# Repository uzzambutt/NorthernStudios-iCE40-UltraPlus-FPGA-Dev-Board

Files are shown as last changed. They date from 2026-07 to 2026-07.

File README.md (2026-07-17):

# NorthernStudios iCE40-UltraPlus FPGA Dev Board (V2)

<p align="center">
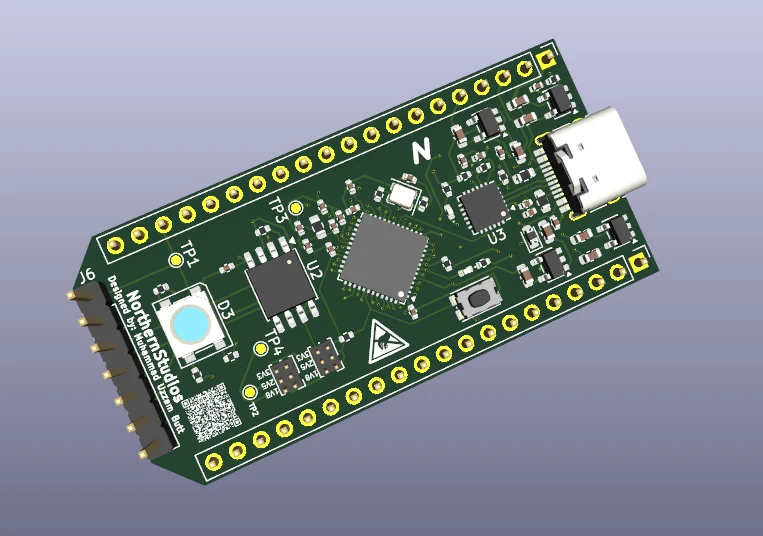
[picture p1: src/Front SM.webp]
NorthernStudios iCE40-UltraPlus FPGA Dev Board V2 - Front Soldermask
  
</p>

<p align="center">
  <b>Designed by: Muhammad Uzzam Butt // Made for Macondo</b>
</p>

<p align="center">
  <a href="https://kicad.org">
    
  </a>
  <a href="https://www.oshwa.org/">
    
  </a>
  <a href="LICENSE">
    
  </a>
</p>

---

## 🌟 Overview

The **NorthernStudios iCE40-UltraPlus FPGA Dev Board (V2)** is a compact, open-source development board designed around the **Lattice iCE40 UltraPlus (iCE40UP5K)** FPGA. Engineered specifically for the **Hack Club Macondo** initiative, this board is tailored for low-power edge computing, machine learning (TinyML), RISC-V softcores, and rapid hardware development.

Featuring an onboard USB-to-UART bridge, a high-capacity 128M-bit SPI Flash, and a highly stable multi-rail power system, it offers a complete, unrestricted environment for developers.

---

## 🛠️ Hardware Specifications

### 🧠 Core FPGA: Lattice iCE40UP5K
* **Logic Cells**: 5,280 Look-Up Tables (LUTs)
* **Block RAM (BRAM)**: 120 Kbit
* **Single-Port RAM (SPRAM)**: 1,024 Kbit (128 KB, ideal for microcontroller program memory)
* **DSP Blocks**: 8 (16x16 multiplier + 32-bit accumulator)
* **Hardened IP**: 2x I2C, 2x SPI
* **Constant Current Drivers**: 3x 24mA dedicated driver outputs (suited for RGB LED control)

### 🔌 Key Components
| Component | Function | Description |
| :--- | :--- | :--- |
| **FPGA** | [Lattice iCE40UP5K-SG48ITR](https://www.latticesemi.com/Products/FPGAandCPLD/iCE40UltraPlus) | SG48 package, 48-pin QFN, highly integrated low-power FPGA. |
| **USB-to-UART Bridge** | [Silicon Labs CP2102N](https://www.silabs.com/interface/usb-bridges/usbtouart/device.cp2102n-a02-gqfn24) | High-speed USB-to-UART bridge for programming and serial debugging via USB-C. |
| **SPI Flash** | Winbond W25Q128JVS (128M-bit / 16MB) | Stores FPGA configuration bitstreams and extra user data or filesystem blocks. |
| **Reference Oscillator** | Seiko Epson SG-210STF (12 MHz) | Ultra-precise active crystal oscillator providing a stable system reference clock. |
| **Power Regulators** | Diodes Inc. AP2112K LDOs | Generates +1.2V (Core), +1.8V (PLL/VCC), +2.5V (Auxiliary), and +3.3V (I/O & Flash) from USB +5V. |
| **USB Connector** | USB Type-C Receptacle (14-Pin) | Handles 5V power supply, programming interface, and UART communications. |

---

## 🎛️ Onboard Interfaces & I/O
* **RGB LED**: Dedicated addressable RGB LED (LED_ARGB) connected to the FPGA's constant current outputs for status and visualization.
* **User I/O**: Multi-pin expansion breakout headers featuring standard 0.1" pitch GPIO pins.
* **Tactile Buttons**:
  * Reset Button
  * User Programmable Button

---

## 📐 PCB Design & Layers

This PCB is designed as a high-density, **4-layer board** utilizing KiCad to ensure clean signal routing, stable ground planes, and dedicated power rails. 

### 🔍 Outer Silkscreen & Soldermask
* **Front View (Main Thumbnail)**:
  Front Soldermask
* **Back View**:
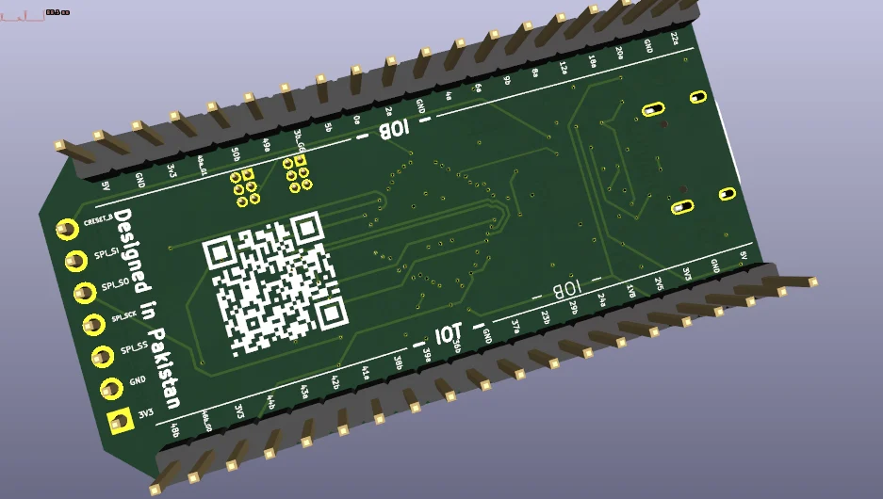
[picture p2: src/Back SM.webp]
Back Soldermask
  

### 🥞 Internal Copper Layer Stackup
* **Layer 1 (L1 - Top Copper / Signals)**:
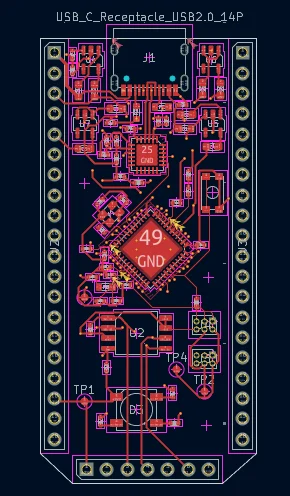
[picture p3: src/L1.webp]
Layer 1 Top Copper
  
* **Layer 2 (L2 - Inner Ground Plane)**:
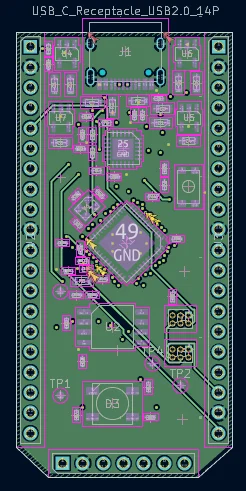
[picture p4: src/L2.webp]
Layer 2 Ground Plane
  
* **Layer 3 (L3 - Inner Power Plane)**:
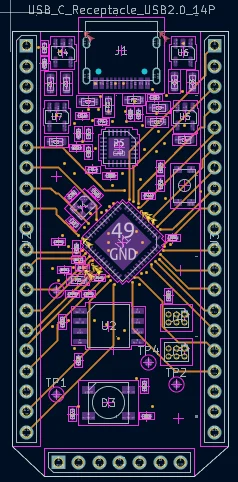
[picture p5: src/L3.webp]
Layer 3 Power Plane
  
* **Layer 4 (L4 - Bottom Copper / Signals)**:
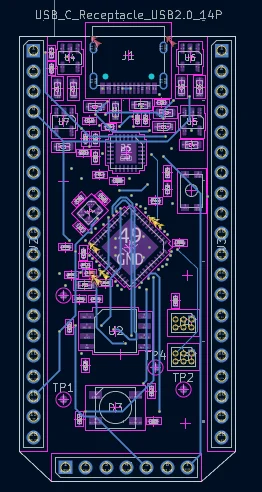
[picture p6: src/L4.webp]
Layer 4 Bottom Copper
  

---

## 📂 Repository Structure

```
├── Models/                     # 3D step models of components
│   └── ICE40UP5K-SG48ITR50.STEP
├── NS FPGA V2 iCE/             # KiCad Project Files
│   ├── NS FPGA V2 iCE.kicad_pro   # KiCad Project File
│   ├── NS FPGA V2 iCE.kicad_sch   # Schematic Sheet
│   └── NS FPGA V2 iCE.kicad_pcb   # PCB Layout
├── src/                        # Graphic assets and layer renders
│   ├── Front SM.webp           # Front Soldermask render
│   ├── Back SM.webp            # Back Soldermask render
│   ├── L1.webp                 # Top Copper Layer render
│   ├── L2.webp                 # Inner Ground Plane render
│   ├── L3.webp                 # Inner Power Plane render
│   └── L4.webp                 # Bottom Copper Layer render
├── .gitignore                  # Gitignore rules for KiCad & system files
├── LICENSE                     # MIT License details
└── README.md                   # Project documentation
```

---

## 🚀 Getting Started

### 💻 Open Source Toolchain Setup
The Lattice iCE40 UltraPlus is fully supported by the open-source FPGA toolchain, providing quick compilation and programming:

1. **Synthesis**: [Yosys](https://github.com/YosysHQ/yosys)
2. **Place & Route**: [nextpnr](https://github.com/YosysHQ/nextpnr) (using target `--up5k`)
3. **Bitstream Packing**: [icepack](https://github.com/YosysHQ/icestorm)
4. **Programming**: [iceprog](https://github.com/YosysHQ/icestorm)

*Note: You can also use Lattice's proprietary IDE **Lattice Radiant** or **iCEcube2**.*

### 🛠️ Cloning the Project
```bash
git clone https://github.com/uzzambutt/NorthernStudios-iCE40-UltraPlus-FPGA-Dev-Board.git
```

---

## 📜 License

This project is licensed under the **MIT License**. For details, see the [LICENSE](LICENSE) file.

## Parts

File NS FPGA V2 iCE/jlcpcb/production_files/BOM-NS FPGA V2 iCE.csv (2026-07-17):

Comment | Designator | Footprint | LCSC | Quantity
0.1uF | C10,C11,C14,C18,C19,C20,C21,C22,C23,C24,C26 | C_0402_1005Metric | C141382 | 11
1.5k | R12,R13,R14,R17 | R_0402_1005Metric | C25867 | 4
100 | R8 | R_0603_1608Metric | C22775 | 1
100nF | C15,C17 | C_0402_1005Metric | C1525 | 2
10k | R10,R11,R15,R16,R6,R7 | R_0402_1005Metric | C25531 | 6
10uF | C16 | C_0402_1005Metric | C15525 | 1
10uF | C1,C2,C3,C4,C5,C6,C7,C8 | C_0603_1608Metric | C19702 | 8
1k | R1 | R_0402_1005Metric | C25543 | 1
1uF | C25 | C_0402_1005Metric | C52923 | 1
22.1k | R5 | R_0402_1005Metric | C43473 | 1
4.7uF | C12,C13,C9 | C_0402_1005Metric | C23733 | 3
47.5k | R4 | R_0402_1005Metric | C137974 | 1
5.1k | R2,R3 | R_0603_1608Metric | C23186 | 2
AP2112K-1.2 | U5 | SOT-23-5 | C460310 | 1
AP2112K-1.8 | U7 | SOT-23-5 | C3021123 | 1
AP2112K-2.5 | U6 | SOT-23-5 | C49451993 | 1
AP2112K-3.3 | U4 | SOT-23-5 | C51118 | 1
CP2102N-Axx-xQFN24 | U3 | QFN-24-1EP_4x4mm_P0.5mm_EP2.6x2.6mm | C969151 | 1
D_Schottky | D1 | D_0603_1608Metric | C6770543 | 1
ICE40UP5K-SG48ITR | U1 | QFN-48-1EP_7x7mm_P0.5mm_EP5.1x5.1mm | C2678152 | 1
LED | D2,D4 | LED_0402_1005Metric | C130723 | 2
LED_ARGB | D3 | LED_RGB_Wuerth-PLCC4_3.2x2.8mm_150141M173100 | C7288905 | 1
R22 | R9 | R_0402_1005Metric | C25092 | 1
SG-210STF | Y1 | Oscillator_SMD_SeikoEpson_SG210-4Pin_2.5x2.0mm | C728996 | 1
SW_Push | SW1 | SW_Push_1P1T_NO_CK_KMR2 | C221679 | 1
USB_C_Receptacle_USB2.0_14P | J1 | USB_C_Receptacle_HRO_TYPE-C-31-M-12 | C2894897 | 1
W25Q128JVS | U2 | SOIC-8_5.3x5.3mm_P1.27mm | C97521 | 1
Conn_02x03_Odd_Even | J5 | PinHeader_2x03_P1.00mm_Vertical |  | 1
Conn_02x03_Odd_Even | J4 | PinHeader_2x03_P1.00mm_Vertical |  | 1
TestPoint_Small | TP4 | TestPoint_Pad_D1.0mm |  | 1
TestPoint_Small | TP3 | TestPoint_Pad_D1.0mm |  | 1
TestPoint_Small | TP2 | TestPoint_Pad_D1.0mm |  | 1
TestPoint_Small | TP1 | TestPoint_Pad_D1.0mm |  | 1
Conn_01x07_Pin | J6 | PinHeader_1x07_P2.54mm_Vertical |  | 1
Conn_01x20_Pin | J3 | PinHeader_1x20_P2.54mm_Vertical |  | 1
Conn_01x20_Pin | J2 | PinHeader_1x20_P2.54mm_Vertical |  | 1

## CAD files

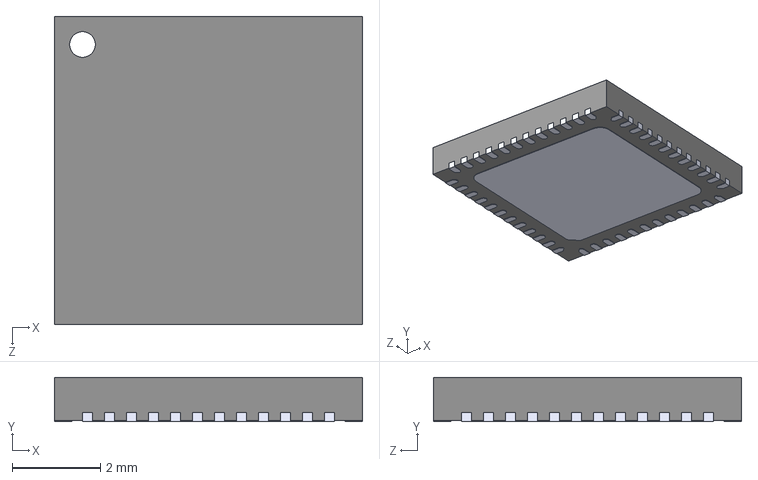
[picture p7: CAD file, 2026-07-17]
Models/ICE40UP5K-SG48ITR50.STEP
7.00 x 1.00 x 7.00 mm

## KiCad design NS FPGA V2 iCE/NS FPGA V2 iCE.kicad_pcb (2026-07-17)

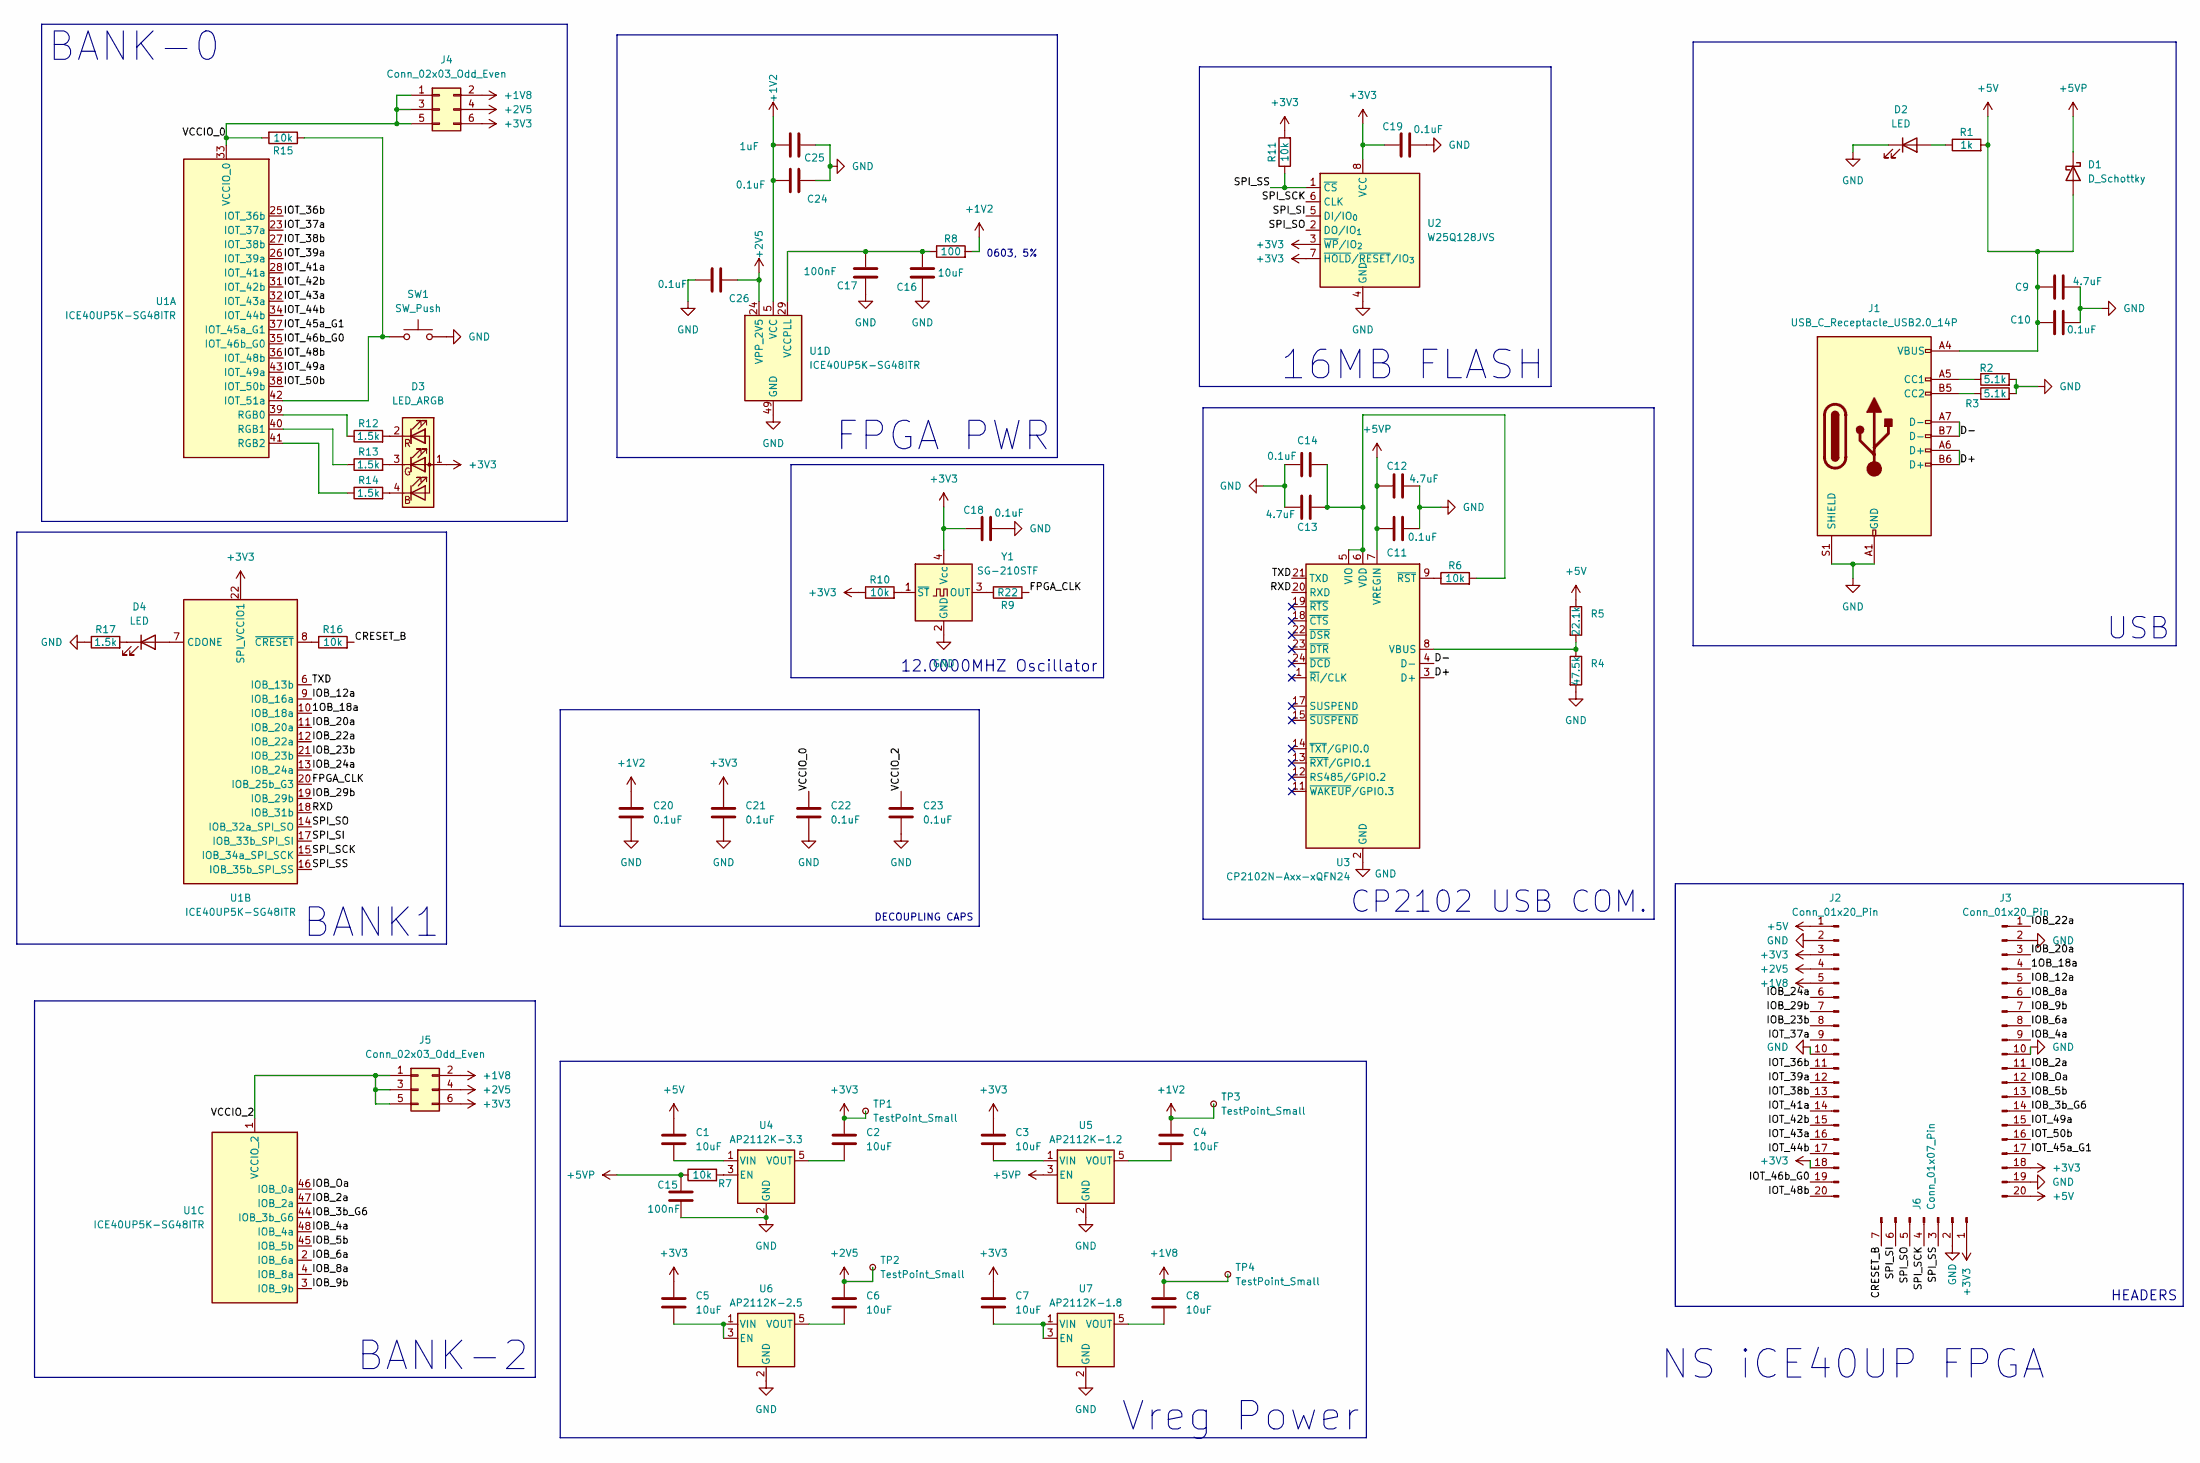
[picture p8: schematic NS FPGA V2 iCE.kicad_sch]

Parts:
C1, C2, C3, C4, C5, C6, C7, C8: 10uF; C_0603_1608Metric
C9, C12, C13: 4.7uF; C_0402_1005Metric
C10, C11, C14, C18, C19, C20, C21, C22, C23, C24, C26: 0.1uF; C_0402_1005Metric
C15, C17: 100nF; C_0402_1005Metric
C16: 10uF; C_0402_1005Metric
C25: 1uF; C_0402_1005Metric
D1: D_Schottky; D_0603_1608Metric
D2, D4: LED; LED_0402_1005Metric
D3: LED_ARGB; LED_RGB_Wuerth-PLCC4_3.2x2.8mm_150141M173100
J1: USB_C_Receptacle_USB2.0_14P; USB_C_Receptacle_HRO_TYPE-C-31-M-12
J2, J3: Conn_01x20_Pin; PinHeader_1x20_P2.54mm_Vertical
J4, J5: Conn_02x03_Odd_Even; PinHeader_2x03_P1.00mm_Vertical
J6: Conn_01x07_Pin; PinHeader_1x07_P2.54mm_Vertical
R1: 1k; R_0402_1005Metric
R2, R3: 5.1k; R_0603_1608Metric
R4: 47.5k; R_0402_1005Metric
R5: 22.1k; R_0402_1005Metric
R6, R7, R10, R11, R15, R16: 10k; R_0402_1005Metric
R8: 100; R_0603_1608Metric
R9: R22; R_0402_1005Metric
R12, R13, R14, R17: 1.5k; R_0402_1005Metric
SW1: SW_Push; SW_Push_1P1T_NO_CK_KMR2
TP1, TP2, TP3, TP4: TestPoint_Small; TestPoint_Pad_D1.0mm
U1: ICE40UP5K-SG48ITR; QFN-48-1EP_7x7mm_P0.5mm_EP5.1x5.1mm
U2: W25Q128JVS; SOIC-8_5.3x5.3mm_P1.27mm
U3: CP2102N-Axx-xQFN24; QFN-24-1EP_4x4mm_P0.5mm_EP2.6x2.6mm
U4: AP2112K-3.3; SOT-23-5
U5: AP2112K-1.2; SOT-23-5
U6: AP2112K-2.5; SOT-23-5
U7: AP2112K-1.8; SOT-23-5
Y1: SG-210STF; Oscillator_SMD_SeikoEpson_SG210-4Pin_2.5x2.0mm

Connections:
+1V2: C4.1, C20.1, C24.1, C25.1, R8.2, TP3.1, U1.5 (VCC), U1.30 (VCC)
+1V8: C8.1, J2.5, J4.2, J5.2, TP4.1
+2V5: C6.1, C26.2, J2.4, J4.4, J5.4, TP2.1, U1.24 (VPP_2V5)
+3V3: C2.1, C3.1, C5.1, C7.1, C18.2, C19.2, C21.1, D3.1 (A), J2.3, J2.18, J3.18, J4.6, J5.6, J6.1, R10.1, R11.2, TP1.1, U1.22 (SPI_VCCIO1), U2.3 (~WP/IO_{2}), U2.7 (~HOLD/~RESET/IO_{3}), U2.8 (VCC), Y1.4 (Vcc)
+5V: C1.1, C9.1, C10.1, D1.2 (A), J1.A4 (VBUS), J1.A9 (VBUS), J1.B4 (VBUS), J1.B9 (VBUS), J2.1, J3.20, R1.2, R5.1
+5VP: C11.1, C12.1, C15.2, D1.1 (K), R7.1, U3.7 (VREGIN), U5.3 (EN)
/1OB_18a: J3.4, U1.10 (IOB_18a)
/CRESET_B: J6.7, R16.2
/D+: J1.A6 (D+), J1.B6 (D+), U3.3 (D+)
/D-: J1.A7 (D-), J1.B7 (D-), U3.4 (D-)
/FPGA_CLK: R9.2, U1.20 (IOB_25b_G3)
/IOB_2a: J3.11, U1.47 (IOB_2a)
/IOB_3b_G6: J3.14, U1.44 (IOB_3b_G6)
/IOB_4a: J3.9, U1.48 (IOB_4a)
/IOB_5b: J3.13, U1.45 (IOB_5b)
/IOB_6a: J3.8, U1.2 (IOB_6a)
/IOB_8a: J3.6, U1.4 (IOB_8a)
/IOB_9b: J3.7, U1.3 (IOB_9b)
/IOB_12a: J3.5, U1.9 (IOB_16a)
/IOB_20a: J3.3, U1.11 (IOB_20a)
/IOB_22a: J3.1, U1.12 (IOB_22a)
/IOB_23b: J2.8, U1.21 (IOB_23b)
/IOB_24a: J2.6, U1.13 (IOB_24a)
/IOB_29b: J2.7, U1.19 (IOB_29b)
/IOB_Oa: J3.12, U1.46 (IOB_0a)
/IOT_36b: J2.11, U1.25 (IOT_36b)
/IOT_37a: J2.9, U1.23 (IOT_37a)
/IOT_38b: J2.13, U1.27 (IOT_38b)
/IOT_39a: J2.12, U1.26 (IOT_39a)
/IOT_41a: J2.14, U1.28 (IOT_41a)
/IOT_42b: J2.15, U1.31 (IOT_42b)
/IOT_43a: J2.16, U1.32 (IOT_43a)
/IOT_44b: J2.17, U1.34 (IOT_44b)
/IOT_45a_G1: J3.17, U1.37 (IOT_45a_G1)
/IOT_46b_G0: J2.19, U1.35 (IOT_46b_G0)
/IOT_48b: J2.20, U1.36 (IOT_48b)
/IOT_49a: J3.15, U1.43 (IOT_49a)
/IOT_50b: J3.16, U1.38 (IOT_50b)
/RXD: U1.18 (IOB_31b), U3.20 (RXD)
/SPI_SCK: J6.4, U1.15 (IOB_34a_SPI_SCK), U2.6 (CLK)
/SPI_SI: J6.6, U1.17 (IOB_33b_SPI_SI), U2.5 (DI/IO_{0})
/SPI_SO: J6.5, U1.14 (IOB_32a_SPI_SO), U2.2 (DO/IO_{1})
/SPI_SS: J6.3, R11.1, U1.16 (IOB_35b_SPI_SS), U2.1 (~CS)
/TXD: U1.6 (IOB_13b), U3.21 (TXD)
/VCCIO_0: C22.1, J4.1, J4.3, J4.5, R15.2, U1.33 (VCCIO_0)
/VCCIO_2: C23.1, J5.1, J5.3, J5.5, U1.1 (VCCIO_2)
GND: C9.2, C10.2, C11.2, C12.2, C13.2, C14.2, C15.1, C16.2, C17.2, C18.1, C19.1, C20.2, C21.2, C22.2, C23.2, C24.2, C25.2, C26.1, D2.1 (K), J1.A1 (GND), J1.A12 (GND), J1.B1 (GND), J1.B12 (GND), J1.S1 (SHIELD), J2.2, J2.10, J3.2, J3.10, J3.19, J6.2, R2.2, R3.2, R4.2, R17.1, SW1.2, U1.49 (GND), U2.4 (GND), U3.2 (GND), U3.25 (GND), U4.2 (GND), U5.2 (GND), U6.2 (GND), U7.2 (GND), Y1.2 (GND)
unnamed: D2.2 (A), R1.1
unnamed: D3.4 (BK), R14.2
unnamed: D3.3 (GK), R13.2
unnamed: D3.2 (RK), R12.2
unnamed: D4.2 (A), U1.7 (CDONE)
unnamed: D4.1 (K), R17.2
unnamed: J1.A5 (CC1), R2.1
unnamed: J1.B5 (CC2), R3.1
unnamed: R15.1, SW1.1, U1.42 (IOT_51a)
unnamed: R12.1, U1.39 (RGB0)
unnamed: R13.1, U1.40 (RGB1)
unnamed: R14.1, U1.41 (RGB2)
unnamed: R16.1, U1.8 (~CRESET)
unnamed: C16.1, C17.1, R8.1, U1.29 (VCCPLL)
unnamed: R4.1, R5.2, U3.8 (VBUS)
unnamed: C13.1, C14.1, R6.2, U3.5 (VIO), U3.6 (VDD)
unnamed: R6.1, U3.9 (~RST)
unnamed: R7.2, U4.3 (EN)
unnamed: C1.2, U4.1 (VIN)
unnamed: C2.2, U4.5 (VOUT)
unnamed: C3.2, U5.1 (VIN)
unnamed: C4.2, U5.5 (VOUT)
unnamed: C5.2, U6.1 (VIN), U6.3 (EN)
unnamed: C6.2, U6.5 (VOUT)
unnamed: C7.2, U7.1 (VIN), U7.3 (EN)
unnamed: C8.2, U7.5 (VOUT)
unnamed: R9.1, Y1.3 (OUT)
unnamed: R10.2, Y1.1 (~ST)

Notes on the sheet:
0603, 5%
NS iCE40UP FPGA
BANK-2
FPGA PWR
16MB FLASH
Vreg Power
USB
BANK1
CP2102 USB COM.
BANK-0
12.0000MHZ Oscillator
HEADERS
DECOUPLING CAPS

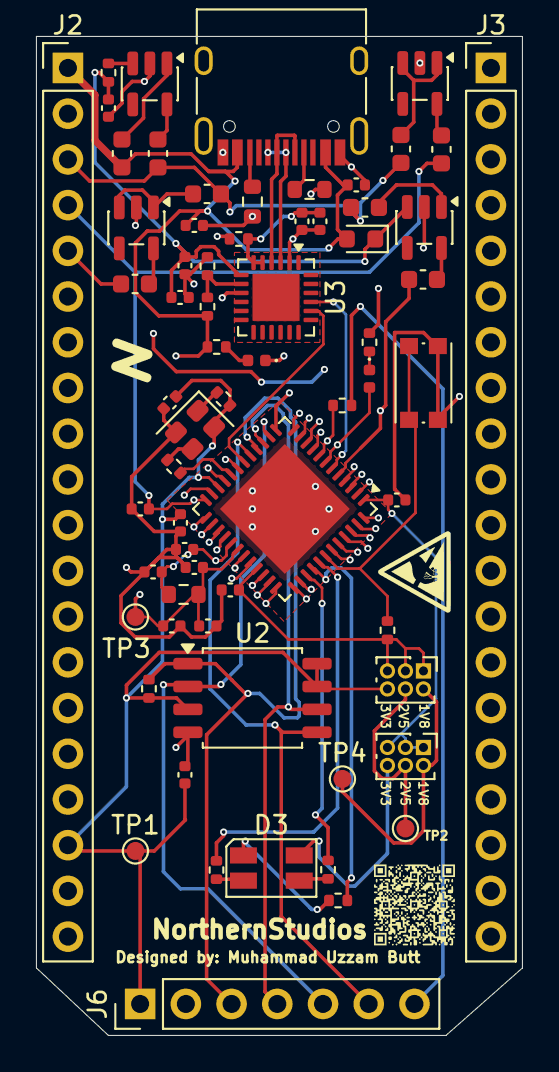
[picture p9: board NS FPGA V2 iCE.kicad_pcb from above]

Board: 4 copper layers, 27.0 x 55.5 mm, 66 parts (0 on the bottom side), 75 nets.

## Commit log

2026-07-16 Initial commit: Set up repository structure with KiCad project files and documentation
    [NS FPGA V2 iCE.kicad_pcb, NS FPGA V2 iCE.kicad_sch]
2026-07-16 drew 30% of the schematic
    [NS FPGA V2 iCE.kicad_sch]
2026-07-16 worked on the chip power delivery and power initialization timing
    [NS FPGA V2 iCE.kicad_sch]
2026-07-16 added split differential voltage input selectors for each FPGA bank, wired up OSC and fixed vreg circuitry
    [NS FPGA V2 iCE.kicad_sch]
2026-07-16 completed drawing
    [NS FPGA V2 iCE.kicad_sch]
2026-07-16 assigned footprints
    [NS FPGA V2 iCE.kicad_sch]
2026-07-17 Completed Placement, Routing and Partial Silkscreen
    [ICE40UP5K-SG48ITR50.STEP, NS FPGA V2 iCE.kicad_pcb, NS FPGA V2 iCE.kicad_sch]
2026-07-17 done with BOM/CPL
    [BOM-NS FPGA V2 iCE.csv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]
2026-07-21 renamed gerber
2026-09-17 added gnd plane
2026-10-30 Update PCB layout and regenerate JLCPCB gerbers
